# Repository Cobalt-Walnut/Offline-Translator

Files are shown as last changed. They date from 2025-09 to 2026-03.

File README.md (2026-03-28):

# EchoLingo
A completely **offline and self-sustaining** translator running on a Raspberry Pi 5 using <ins>VOSK, Piper, and CTranslate2<ins>

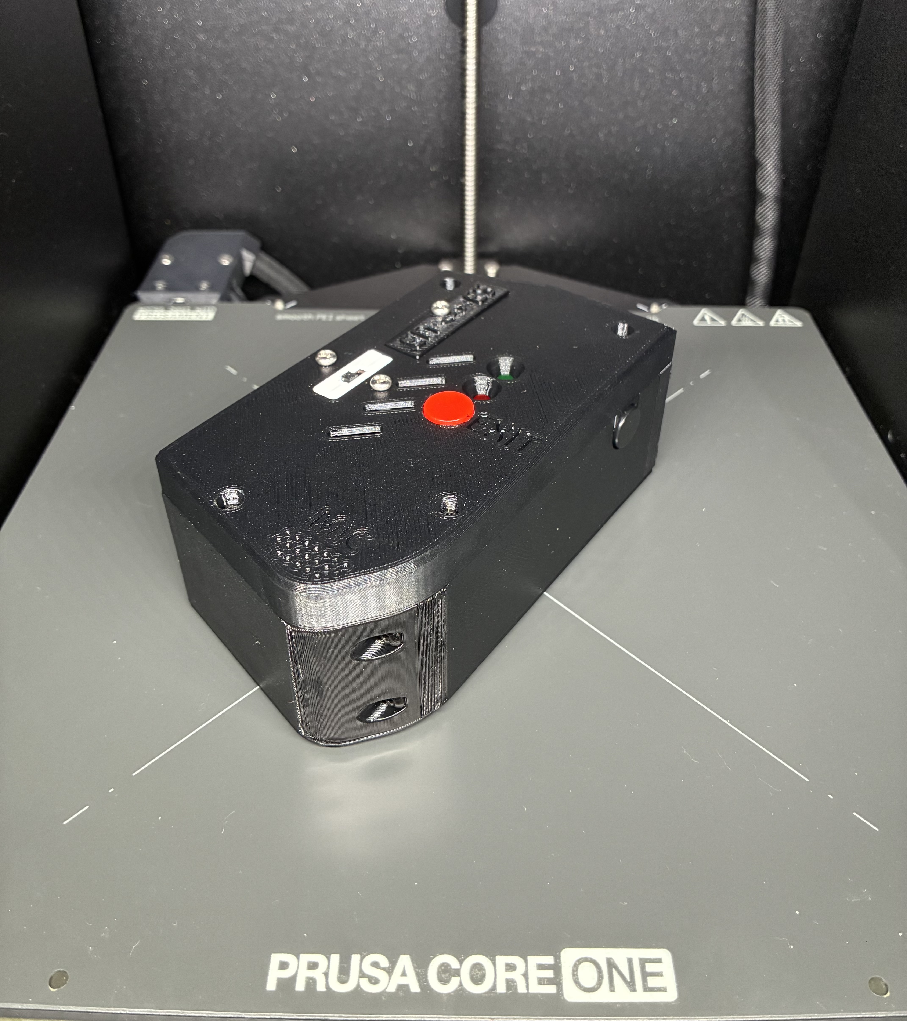
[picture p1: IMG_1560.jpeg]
EchoLingo V3


# Case Components
***1x*** <ins> Echolingo V3 - Bottom.STEP<ins>

***1x*** <ins> Echolingo V3 - Cover V1.STEP<ins>

***1x*** <ins> Echolingo V3 - Pisugar Side Panel V5.STEP<ins>

***1x*** <ins> Echolingo V3 - Amp Panel V5.STEP<ins>

***1x*** <ins> Echolingo V3 - Mic Panel V2.STEP<ins>

***1x*** <ins> Echolingo V3 - Button Securer.STEP<ins>

***2x*** <ins> Echolingo V3 - button.STEP<ins>

***2x*** <ins> Echolingo V3 - Switch Mount Half.STEP<ins>

# Electrical Components
***1x*** <ins> Raspberry Pi 5<ins>

***1x*** <ins> Custom PCB (Working on PCB design in KiCAD)<ins>

***1x*** <ins> [3W 4Ohm Speaker](https://www.amazon.com/Dweii-Loundspeaker-JST-PH2-0mm-2-Electronic-Advertising/dp/B0BTP67F81?th=1)<ins>

***1x*** <ins> [Small USB Microphone](https://www.adafruit.com/product/3367)<ins>

***1x*** <ins> [PiSugar 3 Plus](https://www.amazon.com/PiSugar-Plus-Pwnagotchi-Management-Raspberry/dp/B0FBK89B8H)<ins>

***1x*** <ins> [MAX98357A Amp](https://www.adafruit.com/product/3006)<ins>

# Screws

***6x*** <ins> M3x10 Button Head Screw<ins>

***4x*** <ins> M3x8 Countersunk Head Screw<ins>

***5x*** <ins> M3x6 Countersunk Head Screw<ins>

***2x*** <ins> M3x8 Button Head Screw<ins>

***3x*** <ins> M3x6 Button Head Screw<ins>

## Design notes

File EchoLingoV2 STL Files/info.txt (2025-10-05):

For one case, you need one of the following:
  Translator Case - Bottom V2.stl
  Translator Case - Cover V5.stl
  Translator Case - Top V6.stl
And you need two of the Switch Mount - Half V5.stl

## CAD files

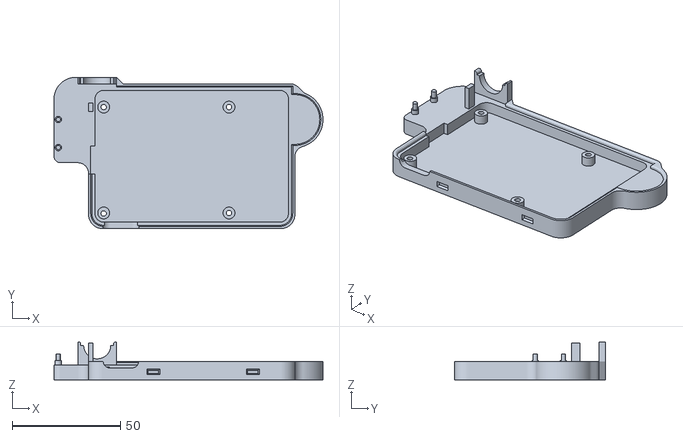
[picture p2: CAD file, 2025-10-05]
EchoLingoV2 STL Files/Translator Case - Bottom V2.stl
124.5 x 70.0 x 17.5

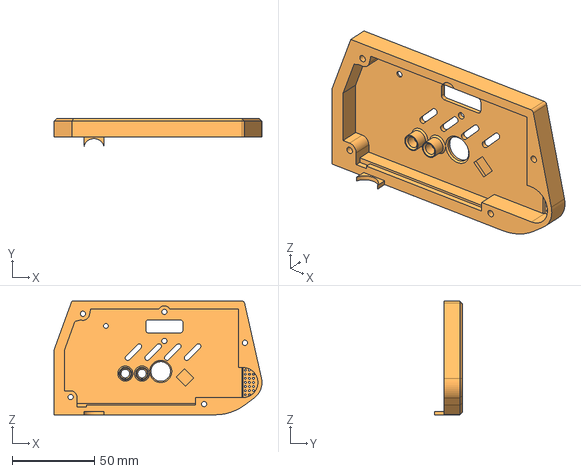
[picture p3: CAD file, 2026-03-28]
EchoLingoV3 STEP Files/Echolingo V3 - Cover V1.step
126.6 x 16.8 x 69.2 mm

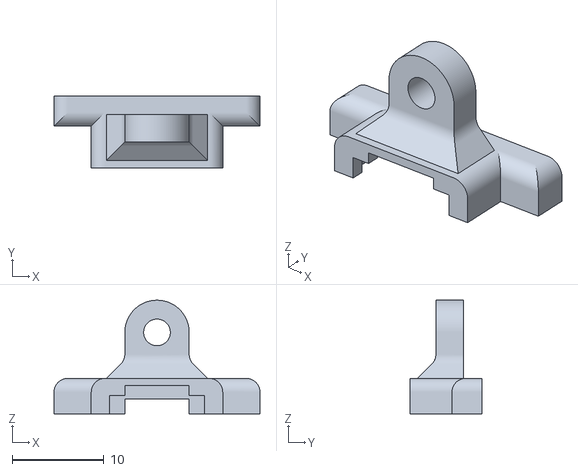
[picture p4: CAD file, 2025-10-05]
EchoLingoV2 STL Files/Switch Mount - Half V5.stl
22.4 x 7.80 x 12.4

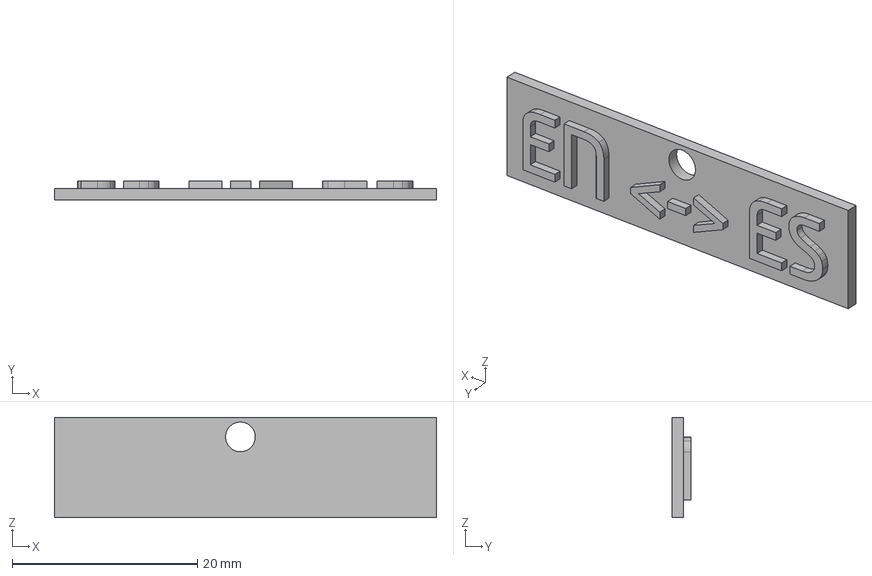
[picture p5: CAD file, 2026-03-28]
EchoLingoV3 STEP Files/Echolingo V3 - EN-ES Lang-Label.step
41.2 x 2.00 x 10.8 mm

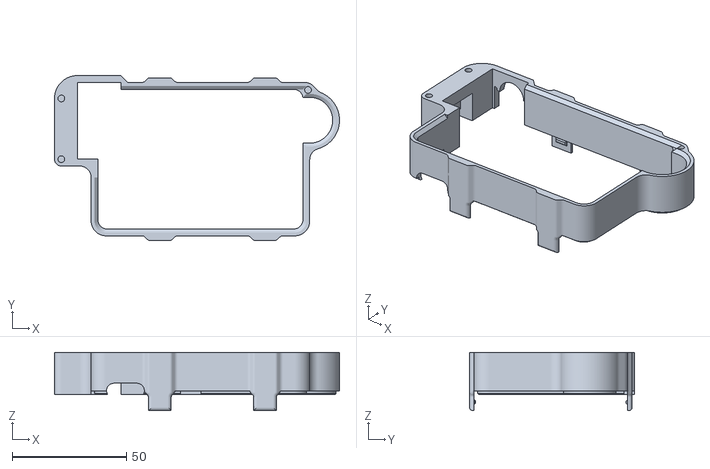
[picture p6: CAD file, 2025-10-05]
EchoLingoV2 STL Files/Translator Case - Top V6.stl
124.5 x 72.0 x 25.5

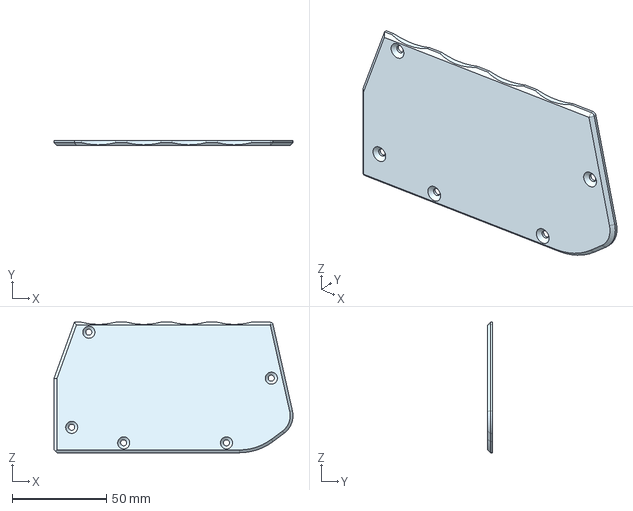
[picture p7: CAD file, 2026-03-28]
EchoLingoV3 STEP Files/Echolingo V3 - Bottom.step
126.6 x 2.60 x 69.2 mm

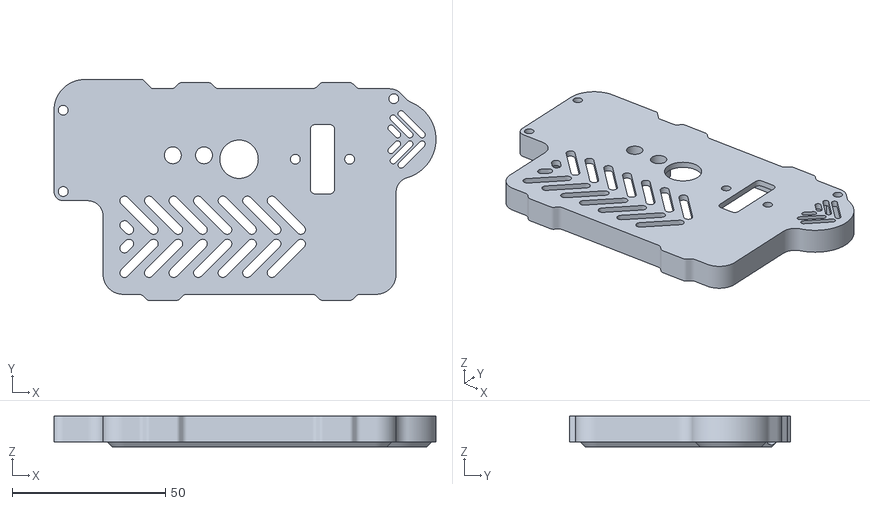
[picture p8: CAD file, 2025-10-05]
EchoLingoV2 STL Files/Translator Case - Cover V5.stl
124.5 x 72.0 x 10.0

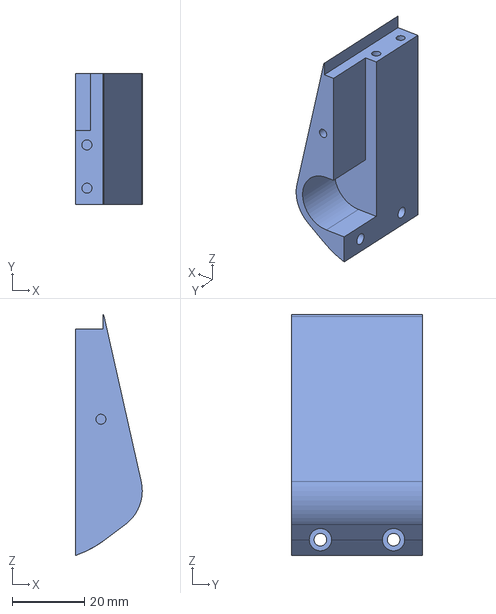
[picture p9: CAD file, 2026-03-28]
EchoLingoV3 STEP Files/Echolingo V3 - Mic Panel V2.step
18.5 x 36.3 x 66.9 mm

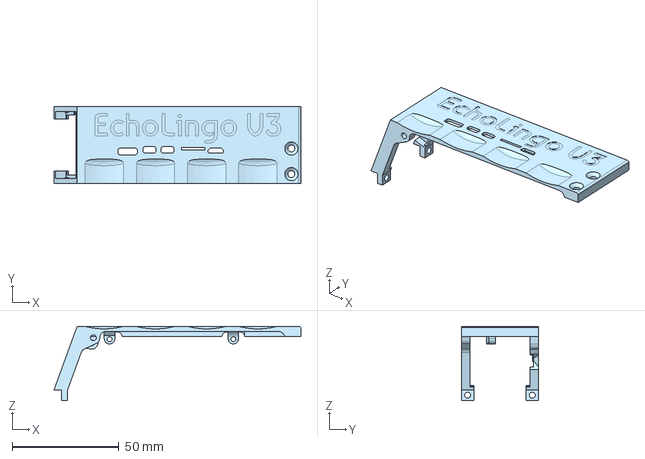
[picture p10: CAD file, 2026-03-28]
EchoLingoV3 STEP Files/Echolingo V3 - Pisugar Side Panel V5.step
115.8 x 36.3 x 34.7 mm

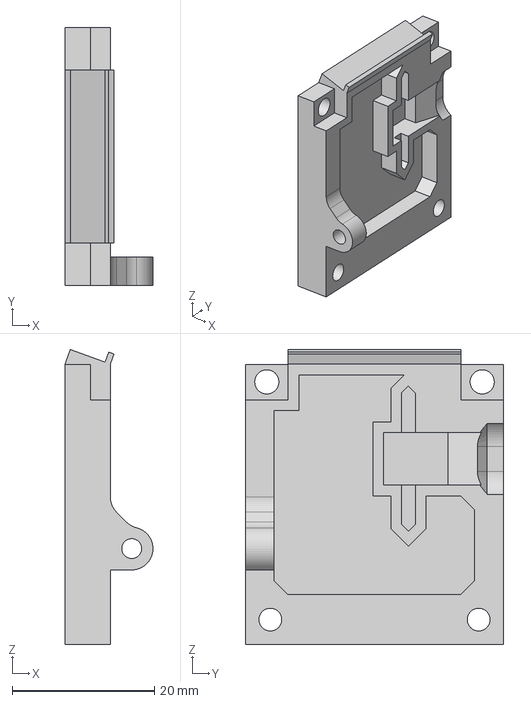
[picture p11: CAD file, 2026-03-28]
EchoLingoV3 STEP Files/Echolingo V3 - Amp Panel V5.step
12.4 x 36.3 x 41.5 mm

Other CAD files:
EchoLingoV3 STEP Files/Echolingo V3 - Switch Mount Half.step

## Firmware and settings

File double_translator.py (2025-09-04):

from gpiozero import LED, Button, DigitalInputDevice
import time
import queue
import numpy as np
import sounddevice as sd
import sys
import json
import vosk
import ctranslate2
import sentencepiece as spm
import subprocess
import os
import gc
from deepmultilingualpunctuation import PunctuationModel

# --- Audio Device Settings (with automatic runtime detection) ---

# Output audio devices (speaker)
POSSIBLE_DEVICES = ["plughw:3,0", "plughw:2,0"]
APLAY_DEVICE = None  # to be selected below

def test_audio_device(device):
    """
    Try playing a short silence to test if device exists and is usable.
    Returns True if successful, False otherwise.
    """
    try:
        silence = b'\x00\x00' * (16000 // 10)  # 0.1 seconds silence at 16kHz, mono, 16-bit
        proc = subprocess.run(
            ['aplay', '-D', device, '-f', 'S16_LE', '-r', '16000'],
            input=silence,
            stdout=subprocess.DEVNULL,
            stderr=subprocess.DEVNULL,
            timeout=2
        )
        return proc.returncode == 0
    except Exception:
        return False

def select_audio_device():
    global APLAY_DEVICE
    for device in POSSIBLE_DEVICES:
        if test_audio_device(device):
            APLAY_DEVICE = device
            print(f"Selected output audio device: {APLAY_DEVICE}")
            return
    APLAY_DEVICE = "default"
    print("No valid output device found, falling back to 'default'")

select_audio_device()

# Input audio devices (microphone)
POSSIBLE_INPUT_DEVICES = ["plughw:3,0", "plughw:2,0"]
INPUT_DEVICE = None  # to be selected below

def test_input_device(device):
    """
    Try to open a small input stream to test if the device is valid for recording.
    Returns True if successful, False otherwise.
    """
    try:
        with sd.InputStream(device=device, channels=1, samplerate=16000):
            pass
        return True
    except Exception:
        return False

def select_input_device():
    global INPUT_DEVICE
    for device in POSSIBLE_INPUT_DEVICES:
        if test_input_device(device):
            INPUT_DEVICE = device
            print(f"Selected input audio device: {INPUT_DEVICE}")
            return
    INPUT_DEVICE = None  # fallback to default if none found
    print("No valid input device found; will use default input device")

select_input_device()

# --- GPIO Setup ---
RED_LED_PIN = 22
GREEN_LED_PIN = 27
BUTTON_PIN = 4
SWITCH_PIN = 13
EXIT_BUTTON_PIN = 5  # Exit button on GPIO5

red_led = LED(RED_LED_PIN)
green_led = LED(GREEN_LED_PIN)
record_button = Button(BUTTON_PIN, pull_up=True)
direction_switch = DigitalInputDevice(SWITCH_PIN, pull_up=False)
exit_button = Button(EXIT_BUTTON_PIN, pull_up=True, bounce_time=0.1)  # Debounced

# --- Model Paths ---
VOSK_EN = "vosk_models/vosk-model-small-en-us-0.15"
VOSK_ES = "vosk_models/vosk-model-small-es-0.42"
CT_EN_ES = "./CTranslate/en-es-ctranslate2"
CT_ES_EN = "./CTranslate/es-en-ctranslate2"
SP_EN_ES_SRC = "./CTranslate/opus-mt-en-es/source.spm"
SP_EN_ES_TGT = "./CTranslate/opus-mt-en-es/target.spm"
SP_ES_EN_SRC = "./CTranslate/opus-mt-es-en/source.spm"
SP_ES_EN_TGT = "./CTranslate/opus-mt-es-en/target.spm"
PIPER_ES = "./piper_models/es_ES-davefx-medium.onnx"
PIPER_EN = "./piper_models/en_US-hfc_male-medium.onnx"
PIPER_CONFIG_ES = "./piper_models/es_ES-davefx-medium.onnx.json"
PIPER_CONFIG_EN = "./piper_models/en_US-hfc_male-medium.onnx.json"
PIPER_BIN = "./piper_models/piper/piper"

# Pre-recorded announcement files
MODE_EN_ES_FILE = "./en-es-mode-quieter.wav"
MODE_ES_EN_FILE = "./es-en-mode-quieter.wav"
NO_AUDIO_EN_FILE = "./no_audio-en-quieter.wav"
NO_AUDIO_ES_FILE = "./no_audio-es-quieter.wav"
EXIT_FILE = "./exit1.wav"

# --- Global Model Holders ---
current_direction = None
vosk_model = None
translator = None
sp_source = None
sp_target = None
piper_voice = None
piper_config = None

# --- Punctuation Model ---
punct_model = PunctuationModel(model="kredor/punctuate-all")

# --- Exit flag ---
exit_requested = False

#time.sleep(7)  # Allow some time for audio devices to initialize at startup

def exit_program():
    global exit_requested
    for _ in range(8):
        red_led.toggle()
        time.sleep(0.25)
    play_audio_file(EXIT_FILE)
    exit_requested = True
    print("\nExit button pressed. Cleaning up...")

exit_button.when_pressed = exit_program

def load_models(direction):
    global vosk_model, translator, sp_source, sp_target, piper_voice, piper_config
    unload_models()
    if direction == "en_to_es":
        print("Loading EN->ES models")
        vosk_model = vosk.Model(VOSK_EN)
        translator = ctranslate2.Translator(CT_EN_ES, device="cpu")
        sp_source = spm.SentencePieceProcessor()
        sp_source.load(SP_EN_ES_SRC)
        sp_target = spm.SentencePieceProcessor()
        sp_target.load(SP_EN_ES_TGT)
        piper_voice = PIPER_ES
        piper_config = PIPER_CONFIG_ES
    elif direction == "es_to_en":
        print("Loading ES->EN models")
        vosk_model = vosk.Model(VOSK_ES)
        translator = ctranslate2.Translator(CT_ES_EN, device="cpu")
        sp_source = spm.SentencePieceProcessor()
        sp_source.load(SP_ES_EN_SRC)
        sp_target = spm.SentencePieceProcessor()
        sp_target.load(SP_ES_EN_TGT)
        piper_voice = PIPER_EN
        piper_config = PIPER_CONFIG_EN

def unload_models():
    global vosk_model, translator, sp_source, sp_target
    vosk_model = None
    translator = None
    sp_source = None
    sp_target = None
    gc.collect()

def get_translation_direction():
    return "es_to_en" if direction_switch.value == 1 else "en_to_es"

def play_audio_file(file_path):
    if os.path.exists(file_path):
        subprocess.run(["aplay", "-D", APLAY_DEVICE, file_path])
    else:
        print(f"Audio file missing: {file_path}")

def play_mode_announcement(direction):
    file_path = MODE_ES_EN_FILE if direction == "es_to_en" else MODE_EN_ES_FILE
    play_audio_file(file_path)

def play_no_audio(direction):
    if direction == "en_to_es":
        play_audio_file(NO_AUDIO_EN_FILE)
    else:
        play_audio_file(NO_AUDIO_ES_FILE)

def transcribe(audio, samplerate):
    rec = vosk.KaldiRecognizer(vosk_model, samplerate)
    rec.AcceptWaveform(audio.tobytes())
    result = json.loads(rec.FinalResult())
    return result.get("text", "")

def translate(text):
    tokens = sp_source.encode(text, out_type=str)
    tokens.append("</s>")
    results = translator.translate_batch([tokens])
    return sp_target.decode(results[0].hypotheses[0])

def speak(text):
    piper_proc = subprocess.Popen(
        [PIPER_BIN, "--model", piper_voice, "--config", piper_config, "--output-raw"],
        stdin=subprocess.PIPE,
        stdout=subprocess.PIPE
    )
    aplay_proc = subprocess.Popen(
        ["aplay", "-D", APLAY_DEVICE, "-r", "22050", "-f", "S16_LE", "-t", "raw"],
        stdin=piper_proc.stdout
    )
    piper_proc.stdin.write(text.encode("utf-8"))
    piper_proc.stdin.close()
    aplay_proc.wait()
    piper_proc.wait()
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

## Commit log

2026-03-28 Added Echolingo V3 STEP Files
    [Echolingo V3 - Amp Panel V5.step, Echolingo V3 - Bottom.step, Echolingo V3 - Cover V1.step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]
2026-03-28 Add button component to README
